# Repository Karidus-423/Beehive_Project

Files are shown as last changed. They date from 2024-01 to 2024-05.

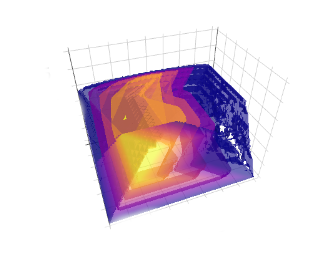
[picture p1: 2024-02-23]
Research_Beehive/images/Beehive-2.png

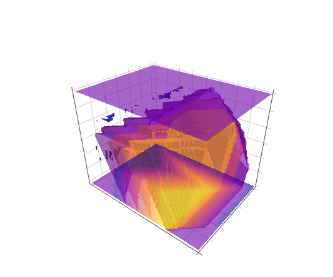
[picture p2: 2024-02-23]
Research_Beehive/images/Beehive-1.png

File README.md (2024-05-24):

# Beehive Project for Kentucky State University
___
The folders build up the project and each of them is responsible for a single 
aspect of it.

- [Datalogger_Beehive](https://github.com/Karidus-423/Beehive_Project/tree/main/Datalogger_Beehive) contains the arduino scripts and the schematics for Pcbs so that the can be printed and the data to get collected.
- [Research_Beehive](https://github.com/Karidus-423/Beehive_Project/tree/main/Research_Beehive) used to analyze the data and make graphs that can be used for science presentations and conferences.
- [Webapp_Beehive](https://github.com/Karidus-423/Beehive_Project/tree/main/Webapp_Beehive) where the webapp in which the output of the Datalogger will be used so that we areble to visualize the recordings of the data.

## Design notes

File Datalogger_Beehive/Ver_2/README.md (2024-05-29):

# Datalogger Version 2
___

### File Structure
- **enclosure**, here you'll find all of the 3D models for the datalogger enclosure.
- **pcb**, schemas, pcb schemas and drill files will be found here.
- **resources**, libraries that are used in making the schemas and pcbs.
- **script**, where the arduino scripts for the datalogger are saved.

## Schematic and PCB Design

At the moment there are 5 main components that are required for the circuit to work.

- Programming Board
- Sensors
- Battery
- Real Time Clock (RTC)
- SD Card Moudule

The main idea is to have the <u>Programming Board</u>, to be connected to a large
battery. The battery must be able to be charged quickly or be swapped quickly. The
sensors need to be configured in a way that the user is able to unplug them relatively
easily try to look for **Audio Jacks** with 3 pins. I have a 3D model of the overall
idea of what it should look like. The parts are already placed on the schematic.

Then the RTC and the SDCard are going to be rather simple as there are some modules
that are able to just connect directly to the feather boards that where ordered.
**Feather Footprint** is a standarized layout of a microcontroller that makes it
easier to get parts for it no matter the brand. The Sparkfun microcontroller and
the adalogger can just be mounted on each other for them to work correctly.

The **Sparkfun Microcontroller** is able to charge whatever battery is connected
to it at a rate of 500mAh. So that takes care of the chargin part. What I remains
are just the design of the PCB to be printed and piecing everything together. The
3D Printers at the university will also work. I will leave two models already printed
at the lab for them to be used as examples or as the enclosure itself.

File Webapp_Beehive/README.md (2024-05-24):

# Beesual: A 3D isograph visualizaton tool for the use of beehives.
Beesual is a visualization tool that renders a 3D isograph using plotly to view the changes in temperature inside a beehive. Built using Dash.

[.csv format for app to work.](https://raw.githubusercontent.com/Karidus-423/Bee_Hive_Webapp/main/sensor_data_hours_updated.csv)

# Bee Project Documentation
____
#### To run the app
```bash
cd Webapp_Beehive
python callbacks.py #Windows py callbacks.py
```

## Main Libraries used
- Numpy
- Pandas
- Scipy
- Plotly

## CSV Format
The CSV format that is generated by the datalogger has 11 columns which are ...
- Sensor Number
- Temperature Sensor Location
    - X
    - Y
    - Z
- Year
- Month
- Hour
- Minute
- Second
- Temperature Value
- Timestamp

<p>I have the full timestamp and the individual components of them like this so that
I'll be easier to extract specific formats when needed and have less code dedicated
to formatting the time in the frontend.</p>

There are three main files for the program to work at the moment.
- callbacks.py
- layout.py
- maindash.py

#### Callbacks
Is the main backend that reads the data and displays it as the 3D image.

Everything before `def update_dataset_and_figures(contents):` is just setup. 
The main building block that lets us speak back to the plotly library is with
the `@app.callback(Output,Input)`. You are able to have n outputs and n inputs by
sorrounding them with [].

`def update_dataset_and_figures(contents):` Is the main function that makes the 
main volume image. The documentation for how to use this is here. [Plotly Volume Plot](https://plotly.com/python/3d-volume-plots/).

Also the component that makes the transistion between the CSV to the graph possible
is...
```python
recording = dataset[dataset['Timestamp'] == first_timestamp]

X = np.linspace(recording['X'].min(), recording['X'].max(), 50)
Y = np.linspace(recording['Y'].min(), recording['Y'].max(), 50)
Z = np.linspace(recording['Z'].min(), recording['Z'].max(), 20)

x, y, z = np.meshgrid(X, Y, Z)

points = np.array((recording['X'], recording['Y'], recording['Z'])).T
temps = recording['Temperature']

newdata = griddata(points, temps, (x, y, z), method='linear')
```

Then depending on the slider values that are inputed we get the collection of dates
in which are then added to an array. That array then build every graph which make
the collection of them so that we can slide them and see it "animated".

#### Layout and Maindash
The layout file is the front end of the app. It uses the Dash Components [Dash Docs](https://dash.plotly.com/).
As the building blocks for the frontend and bootstrap for the styling. One could also
use javascript if you are willing to change it as it a bit hard to follow since everything
is really nested toghether. The **maindash.py** is just used to separate the two
files. The `app = dash.Dash()` is what is needed to run the project. As long as that
is read the project will run.

### Extra Resources
[Mesh Grid Insights](https://stackoverflow.com/questions/36013063/what-is-the-purpose-of-meshgrid-in-numpy)

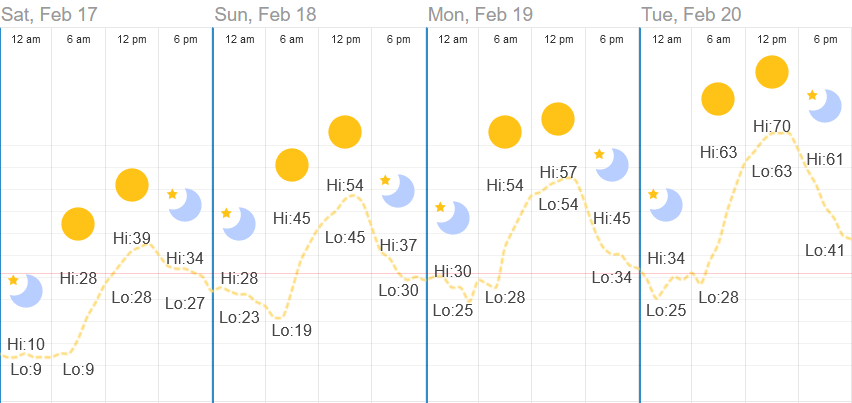
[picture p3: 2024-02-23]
Research_Beehive/images/weather.png

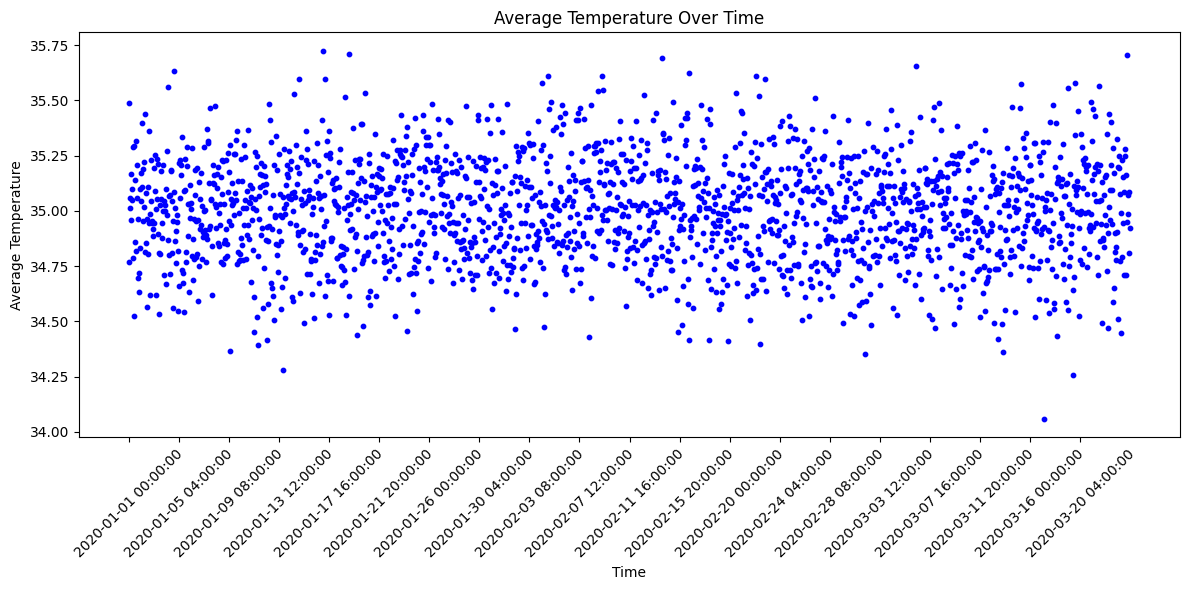
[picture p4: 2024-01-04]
Research_Beehive/images/averageTemp_time.png

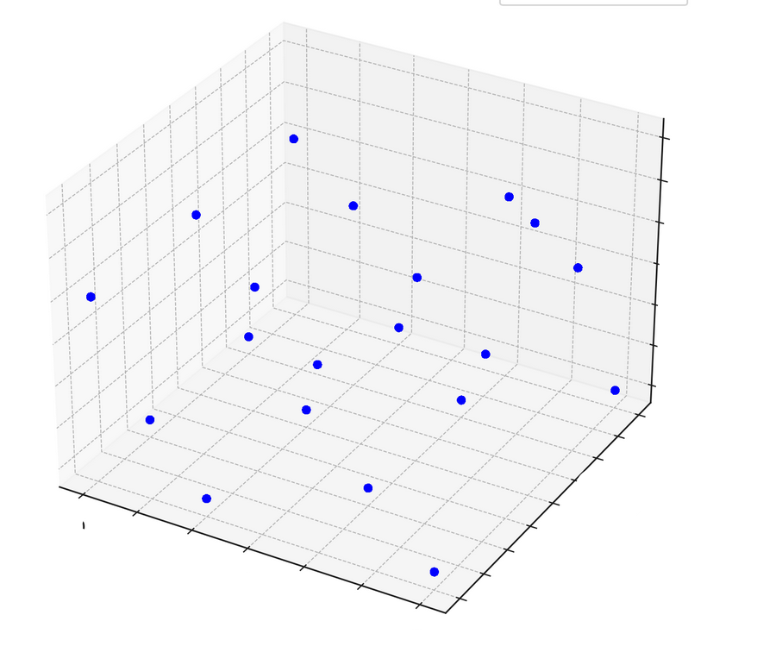
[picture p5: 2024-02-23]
Research_Beehive/images/Positions.png

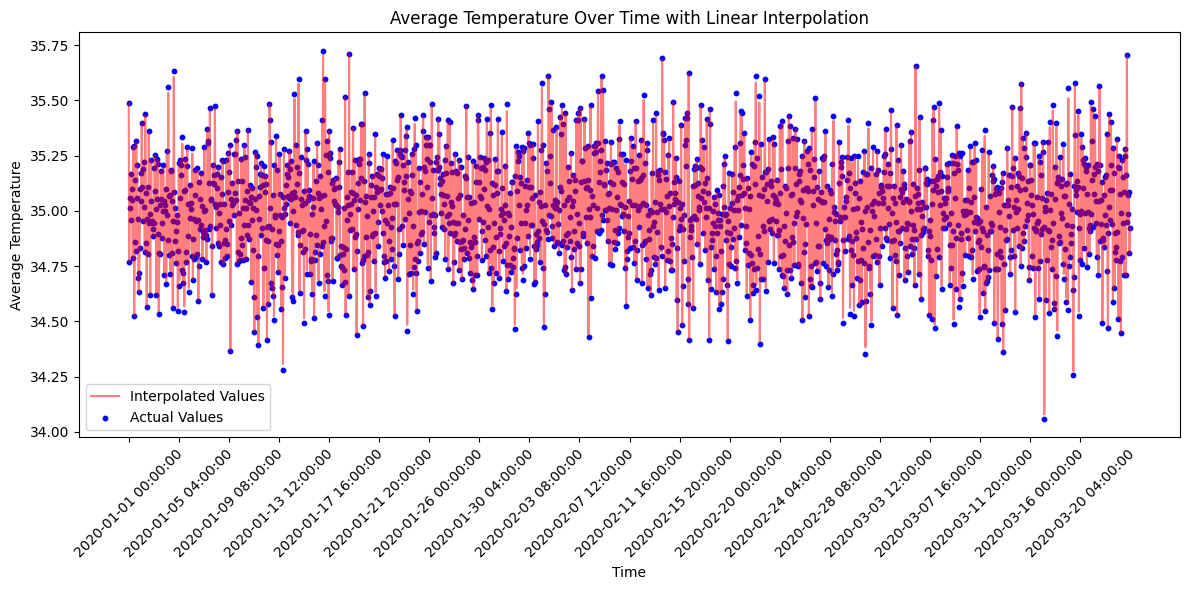
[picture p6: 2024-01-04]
Research_Beehive/images/interpolation.png

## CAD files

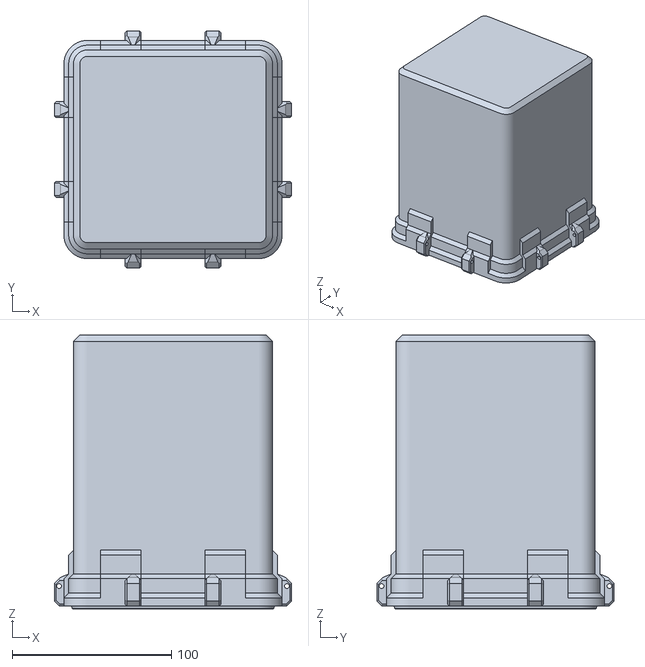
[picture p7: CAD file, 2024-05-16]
Datalogger_Beehive/Ver_2/enclosure/bottom.stl
149.0 x 149.0 x 172.0

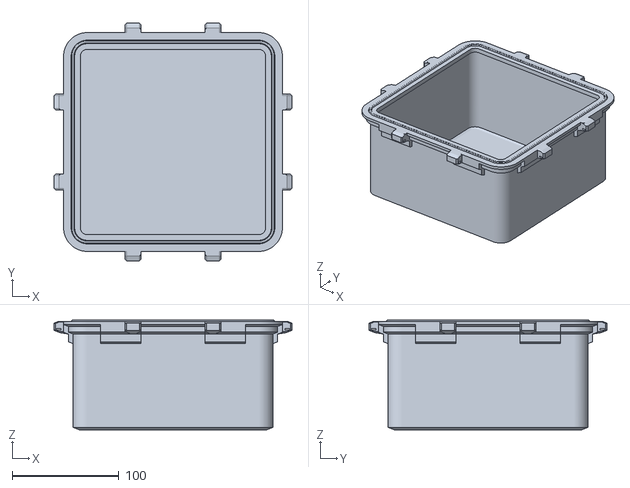
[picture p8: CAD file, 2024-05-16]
Datalogger_Beehive/Ver_2/enclosure/bottom_v2.stl
223.5 x 223.5 x 103.2

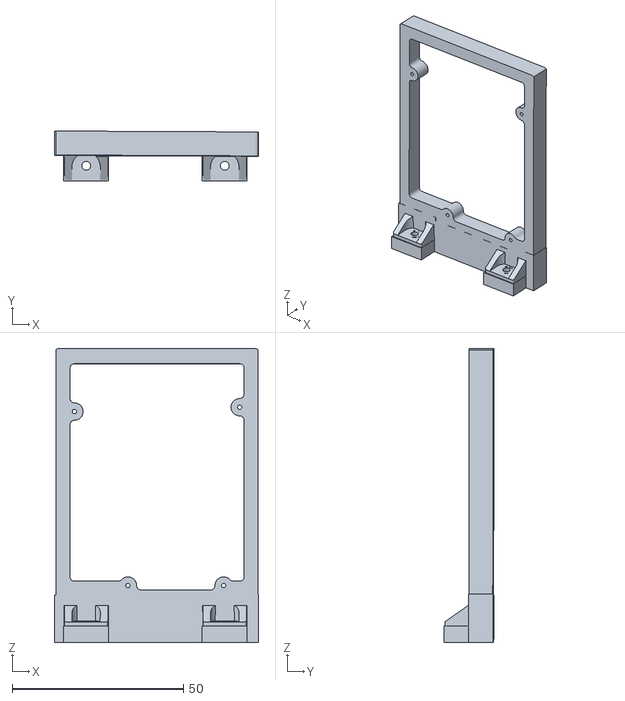
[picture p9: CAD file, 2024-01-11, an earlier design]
Datalogger_Beehive/Ver_1/3D_Models/Arduino_MOUNT.stl
59.6 x 14.6 x 85.8

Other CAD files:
Datalogger_Beehive/Ver_2/enclosure/datalogger_v2_enclosure.blend

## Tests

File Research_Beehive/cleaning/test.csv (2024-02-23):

Sensor_number | X | Y | Z | Year | Month | Day | Hour | Minute | Second | Temperature | Timestamp
11 | 3 | 3 | 0 | 2020 | 1 | 1 | 0 | 0 | 0 | 35.5 | 2020-01-01 00:00:00
3 | 3 | 1 | 0 | 2020 | 1 | 1 | 0 | 0 | 0 | 37.44 | 2020-01-01 00:00:00
4 | 2 | 0 | 1 | 2020 | 1 | 1 | 0 | 0 | 0 | 37.51 | 2020-01-01 00:00:00
5 | 2 | 0 | 1 | 2020 | 1 | 1 | 0 | 0 | 0 | 34.63 | 2020-01-01 00:00:00
6 | 2 | 4 | 1 | 2020 | 1 | 1 | 0 | 0 | 0 | 35.23 | 2020-01-01 00:00:00
7 | 1 | 1 | 2 | 2020 | 1 | 1 | 0 | 0 | 0 | 37.47 | 2020-01-01 00:00:00
8 | 1 | 4 | 0 | 2020 | 1 | 1 | 0 | 0 | 0 | 33.92 | 2020-01-01 00:00:00
9 | 0 | 8 | 2 | 2020 | 1 | 1 | 0 | 0 | 0 | 33.71 | 2020-01-01 00:00:00
10 | 0 | 5 | 1 | 2020 | 1 | 1 | 0 | 0 | 0 | 35.27 | 2020-01-01 00:00:00
13 | 1 | 3 | 0 | 2020 | 1 | 1 | 0 | 0 | 0 | 34.89 | 2020-01-01 00:00:00
14 | 1 | 8 | 2 | 2020 | 1 | 1 | 0 | 0 | 0 | 35.12 | 2020-01-01 00:00:00
15 | 3 | 4 | 1 | 2020 | 1 | 1 | 0 | 0 | 0 | 32.13 | 2020-01-01 00:00:00
12 | 3 | 8 | 0 | 2020 | 1 | 1 | 0 | 0 | 0 | 37.89 | 2020-01-01 00:00:00
18 | 1 | 9 | 2 | 2020 | 1 | 1 | 0 | 0 | 0 | 32.62 | 2020-01-01 00:00:00
20 | 3 | 2 | 0 | 2020 | 1 | 1 | 0 | 0 | 0 | 37.82 | 2020-01-01 00:00:00
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

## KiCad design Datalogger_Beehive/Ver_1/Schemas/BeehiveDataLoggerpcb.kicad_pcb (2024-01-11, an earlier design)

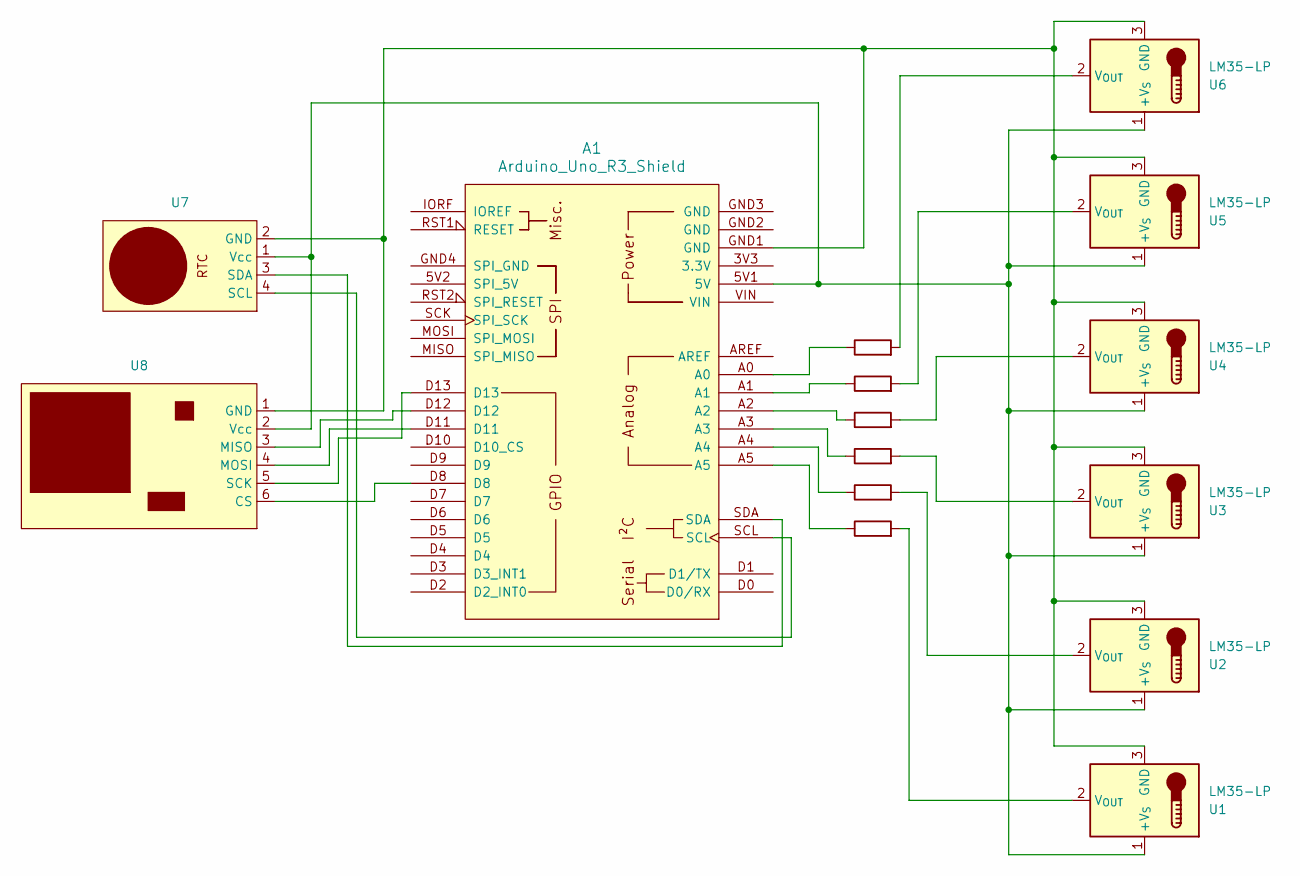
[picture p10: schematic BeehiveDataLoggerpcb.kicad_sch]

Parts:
A1: Arduino_Uno_R3_Shield
R1, R2, R3, R4, R5, R6: R; R_Axial_DIN0207_L6.3mm_D2.5mm_P7.62mm_Horizontal
U1, U2, U3, U4, U5, U6: LM35-LP; TO-92_Inline
U7: PinSocket_1x04_P2.54mm_Vertical
U8: PinSocket_1x06_P2.54mm_Vertical

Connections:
unnamed 0: A1.5V1 (5V), U1.1 (+V_{S}), U2.1 (+V_{S}), U3.1 (+V_{S}), U4.1 (+V_{S}), U5.1 (+V_{S}), U6.1 (+V_{S}), U7.1 (Vcc), U8.2 (Vcc); also elsewhere on the board
unnamed 1: A1.A0, R1.1; also elsewhere on the board
unnamed 2: A1.A1, R2.1; also elsewhere on the board
unnamed 3: A1.A2, R3.1; also elsewhere on the board
unnamed 4: A1.A3, R4.1; also elsewhere on the board
unnamed 5: A1.A4, R5.1; also elsewhere on the board
unnamed 6: A1.A5, R6.1; also elsewhere on the board
unnamed 7: A1.GND1 (GND), U1.3 (GND), U2.3 (GND), U3.3 (GND), U4.3 (GND), U5.3 (GND), U6.3 (GND), U7.2 (GND), U8.1 (GND); also elsewhere on the board
unnamed: R6.2, U1.2 (V_{OUT})
unnamed: R5.2, U2.2 (V_{OUT})
unnamed: R4.2, U3.2 (V_{OUT})
unnamed: R3.2, U4.2 (V_{OUT})
unnamed: R2.2, U5.2 (V_{OUT})
unnamed: R1.2, U6.2 (V_{OUT})
unnamed 14: A1.SCL, U7.4 (SCL); also elsewhere on the board
unnamed 15: A1.SDA, U7.3 (SDA); also elsewhere on the board
unnamed 16: A1.D8, U8.6 (CS); also elsewhere on the board
unnamed 17: A1.D12, U8.3 (MISO); also elsewhere on the board
unnamed 18: A1.D11, U8.4 (MOSI); also elsewhere on the board
unnamed 19: A1.D13, U8.5 (SCK); also elsewhere on the board

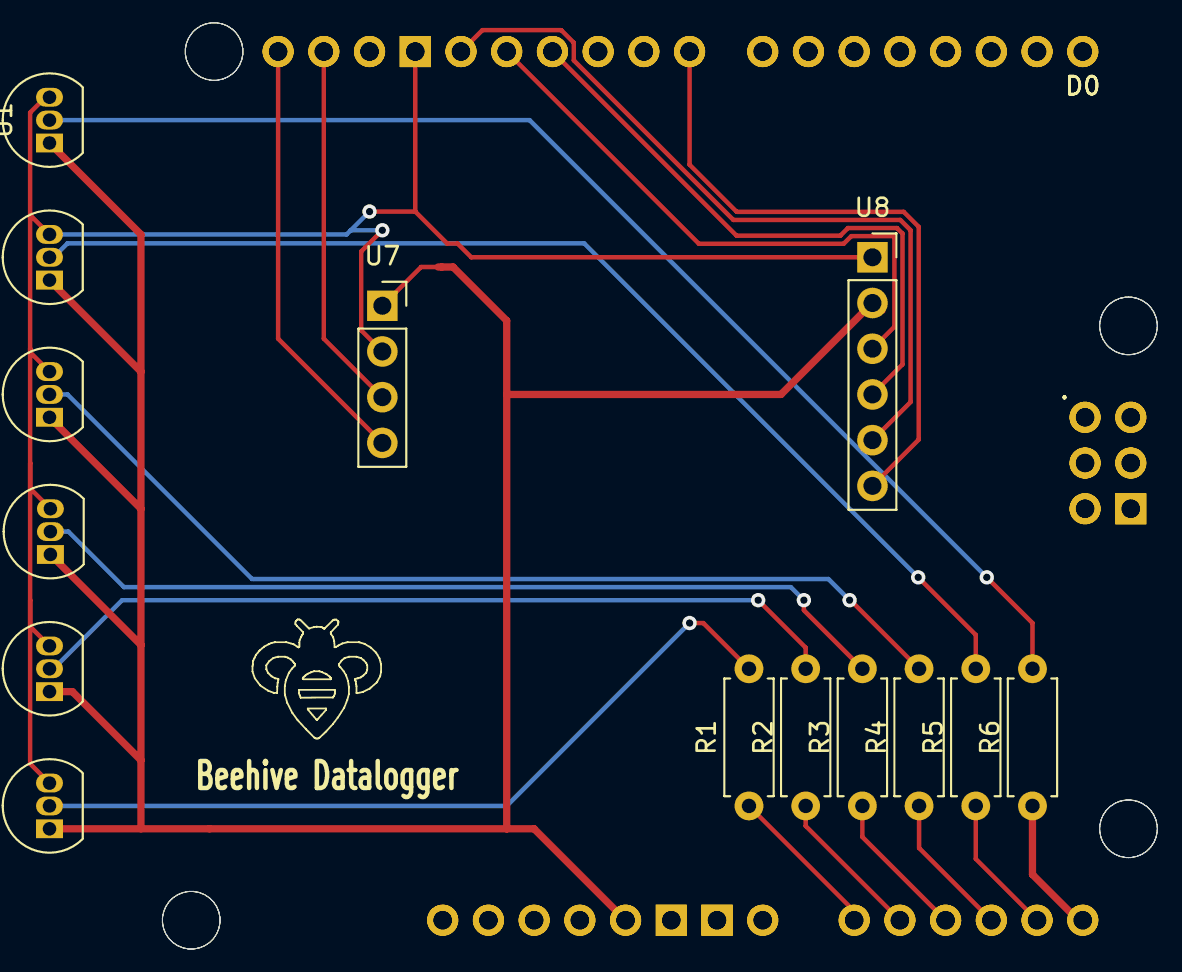
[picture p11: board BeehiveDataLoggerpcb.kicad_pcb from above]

Board: 2 copper layers, 16 parts (0 on the bottom side), 20 nets.

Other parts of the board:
A1#2: Arduino_Uno_R3_Shield

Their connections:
unnamed 0: A1#2.5V1 (5V); also elsewhere on the board
unnamed 1: A1#2.A0; also elsewhere on the board
unnamed 2: A1#2.A1; also elsewhere on the board
unnamed 3: A1#2.A2; also elsewhere on the board
unnamed 4: A1#2.A3; also elsewhere on the board
unnamed 5: A1#2.A4; also elsewhere on the board
unnamed 6: A1#2.A5; also elsewhere on the board
unnamed 7: A1#2.GND1 (GND); also elsewhere on the board
unnamed 14: A1#2.SCL; also elsewhere on the board
unnamed 15: A1#2.SDA; also elsewhere on the board
unnamed 16: A1#2.D8; also elsewhere on the board
unnamed 17: A1#2.D12; also elsewhere on the board
unnamed 18: A1#2.D11; also elsewhere on the board
unnamed 19: A1#2.D13; also elsewhere on the board

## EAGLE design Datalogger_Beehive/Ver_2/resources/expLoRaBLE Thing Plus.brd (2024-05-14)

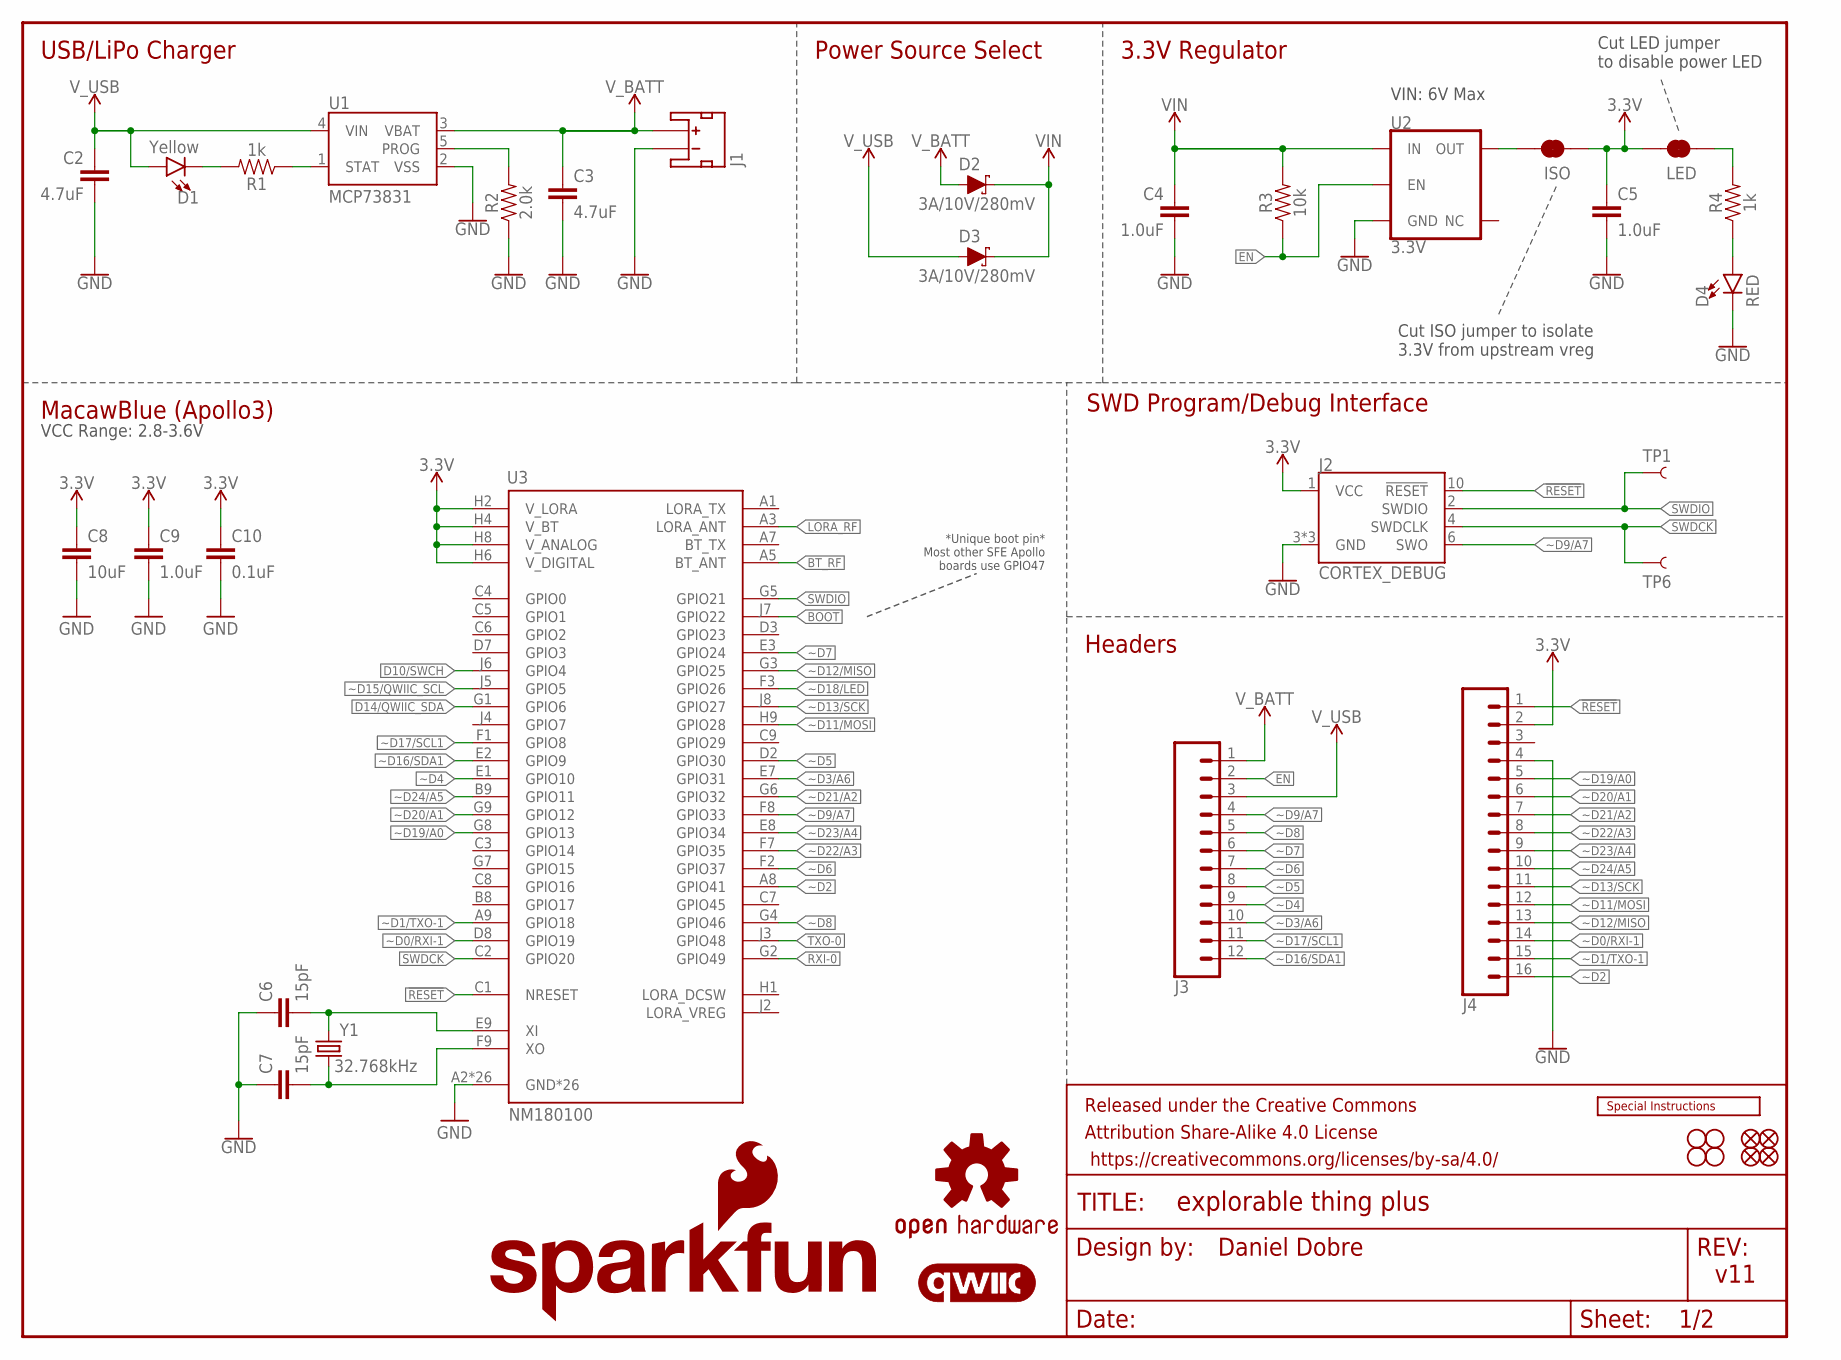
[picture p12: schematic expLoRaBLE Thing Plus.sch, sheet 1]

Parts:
C2, C3: 4.7uF; 0603
C4, C5, C9: 1.0uF; 0603
C6, C7: 15pF; 0603
C8: 10uF; 0603
C10: 0.1uF; 0603
D1: Yellow; LED-0603
D2, D3: 3A/10V/280mV; SOD-323
D4: RED; LED-0603
FD1, FD2, FD3, FD4: FIDUCIALUFIDUCIAL; FIDUCIAL-MICRO
FRAME1: FRAME-LETTER; CREATIVE_COMMONS
H1, H2, H3, H4: STAND-OFF
ISO: JUMPER-SMT_2_NC_TRACE_SILK; SMT-JUMPER_2_NC_TRACE_SILK
J1: JST_2MM_MALE; JST-2-SMD
J2: CORTEX_DEBUG; 2X5-PTH-1.27MM-NO_SILK
J3: CONN_12SM_SQ_NO_SILK; 1X12_SM_SQ_NOSILK
J4: CONN_161X16_SM_SQ_NOSILK; 1X16_SM_SQ_NOSILK
LED: JUMPER-SMT_2_NC_TRACE_SILK; SMT-JUMPER_2_NC_TRACE_SILK
LOGO1: OSHW-LOGOS; OSHW-LOGO-S
LOGO2: QWIIC_LOGO_5MM; QWIIC_5MM
LOGO3: SFE_LOGO_NAME_FLAME.1_INCH; SFE_LOGO_NAME_FLAME_.1
LOGO4: SPECIAL_INSTRUCTIONS-ORDERING; ORDERING_INSTRUCTIONS
R1, R4: 1k; 0603
R2: 2.0k; 0603
R3: 10k; 0603
TP1, TP6: TEST-POINTTP_15TH_THRU; TP_15TH
U1: MCP73831; SOT23-5
U2: 3.3V; SOT23-5
U3: NM180100; LGA81
Y1: 32.768kHz; CRYSTAL-SMD-3.2X1.5MM

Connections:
3.3V: C5.1, C8.1, C9.1, C10.1, ISO.1, J2.1 (VCC), J4.2, LED.2, U3.H2 (V_LORA), U3.H4 (V_BT), U3.H6 (V_DIGITAL), U3.H8 (V_ANALOG); also elsewhere on the board
!RESET: J2.10 (!RESET), J4.1, U3.C1 (NRESET); also elsewhere on the board
BOOT: U3.J7 (GPIO22); also elsewhere on the board
BT_RF: U3.A5 (BT_ANT); also elsewhere on the board
D10/SWCH: U3.J6 (GPIO4); also elsewhere on the board
D14/QWIIC_SDA: U3.G1 (GPIO6); also elsewhere on the board
EN: J3.2, R3.1, U2.3 (EN)
GND: C2.2, C3.2, C4.2, C5.2, C6.1, C7.1, C8.2, C9.2, C10.2, D4.C, J1.1 (-), J2.3 (GND), J2.5 (GND), J2.9 (GND), J4.4, R2.1, U1.2 (VSS), U2.2 (GND), U3.A2 (GND*26), U3.A4 (GND*26), U3.A6 (GND*26), U3.B1 (GND*26), U3.B2 (GND*26), U3.B3 (GND*26), U3.B4 (GND*26), U3.B5 (GND*26), U3.B6 (GND*26), U3.B7 (GND*26), U3.D1 (GND*26), U3.D4 (GND*26), U3.D5 (GND*26), U3.D6 (GND*26), U3.D9 (GND*26), U3.E4 (GND*26), U3.E5 (GND*26), U3.E6 (GND*26), U3.F4 (GND*26), U3.F5 (GND*26), U3.F6 (GND*26), U3.H3 (GND*26), U3.H5 (GND*26), U3.H7 (GND*26), U3.J1 (GND*26), U3.J9 (GND*26); also elsewhere on the board
LORA_RF: U3.A3 (LORA_ANT); also elsewhere on the board
unnamed: R2.2, U1.5 (PROG)
unnamed: C7.2, U3.F9 (XO), Y1.P$2 (2)
unnamed: D1.C, R1.2
unnamed: R1.1, U1.1 (STAT)
unnamed: LED.1, R4.2
unnamed: C6.2, U3.E9 (XI), Y1.P$1 (1)
unnamed: D4.A, R4.1
unnamed: ISO.2, U2.5 (OUT)
RXI-0: U3.G2 (GPIO49); also elsewhere on the board
SWDCK: J2.4 (SWDCLK), TP6.P$1, U3.C2 (GPIO20)
SWDIO: J2.2 (SWDIO), TP1.P$1, U3.G5 (GPIO21)
TXO-0: U3.J3 (GPIO48); also elsewhere on the board
VIN: C4.1, D2.C, D3.C, R3.2, U2.1 (IN)
V_BATT: C3.1, D2.A, J1.2 (+), J3.1, U1.3 (VBAT)
V_USB: C2.1, D1.A, D3.A, J3.3, U1.4 (VIN); also elsewhere on the board
~D0/RXI-1: J4.14, U3.D8 (GPIO19)
~D1/TXO-1: J4.15, U3.A9 (GPIO18)
~D2: J4.16, U3.A8 (GPIO41)
~D3/A6: J3.10, U3.E7 (GPIO31)
~D4: J3.9, U3.E1 (GPIO10)
~D5: J3.8, U3.D2 (GPIO30)
~D6: J3.7, U3.F2 (GPIO37)
~D7: J3.6, U3.E3 (GPIO24)
~D8: J3.5, U3.G4 (GPIO46)
~D9/A7: J2.6 (SWO), J3.4, U3.F8 (GPIO33)
~D11/MOSI: J4.12, U3.H9 (GPIO28)
~D12/MISO: J4.13, U3.G3 (GPIO25)
~D13/SCK: J4.11, U3.J8 (GPIO27)
~D15/QWIIC_SCL: U3.J5 (GPIO5); also elsewhere on the board
~D16/SDA1: J3.12, U3.E2 (GPIO9)
~D17/SCL1: J3.11, U3.F1 (GPIO8)
~D18/LED: U3.F3 (GPIO26); also elsewhere on the board
~D19/A0: J4.5, U3.G8 (GPIO13)
~D20/A1: J4.6, U3.G9 (GPIO12)
~D21/A2: J4.7, U3.G6 (GPIO32)
~D22/A3: J4.8, U3.F7 (GPIO35)
~D23/A4: J4.9, U3.E8 (GPIO34)
~D24/A5: J4.10, U3.B9 (GPIO11)

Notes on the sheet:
SWD Program/Debug Interface
Headers
MacawBlue (Apollo3)
USB/LiPo Charger
Power Source Select
3.3V Regulator
VIN: 6V Max
Daniel Dobre
v11
Cut LED jumper to disable power LED
Cut ISO jumper to isolate 3.3V from upstream vreg
VCC Range: 2.8-3.6V
*Unique boot pin* Most other SFE Apollo boards use GPIO47

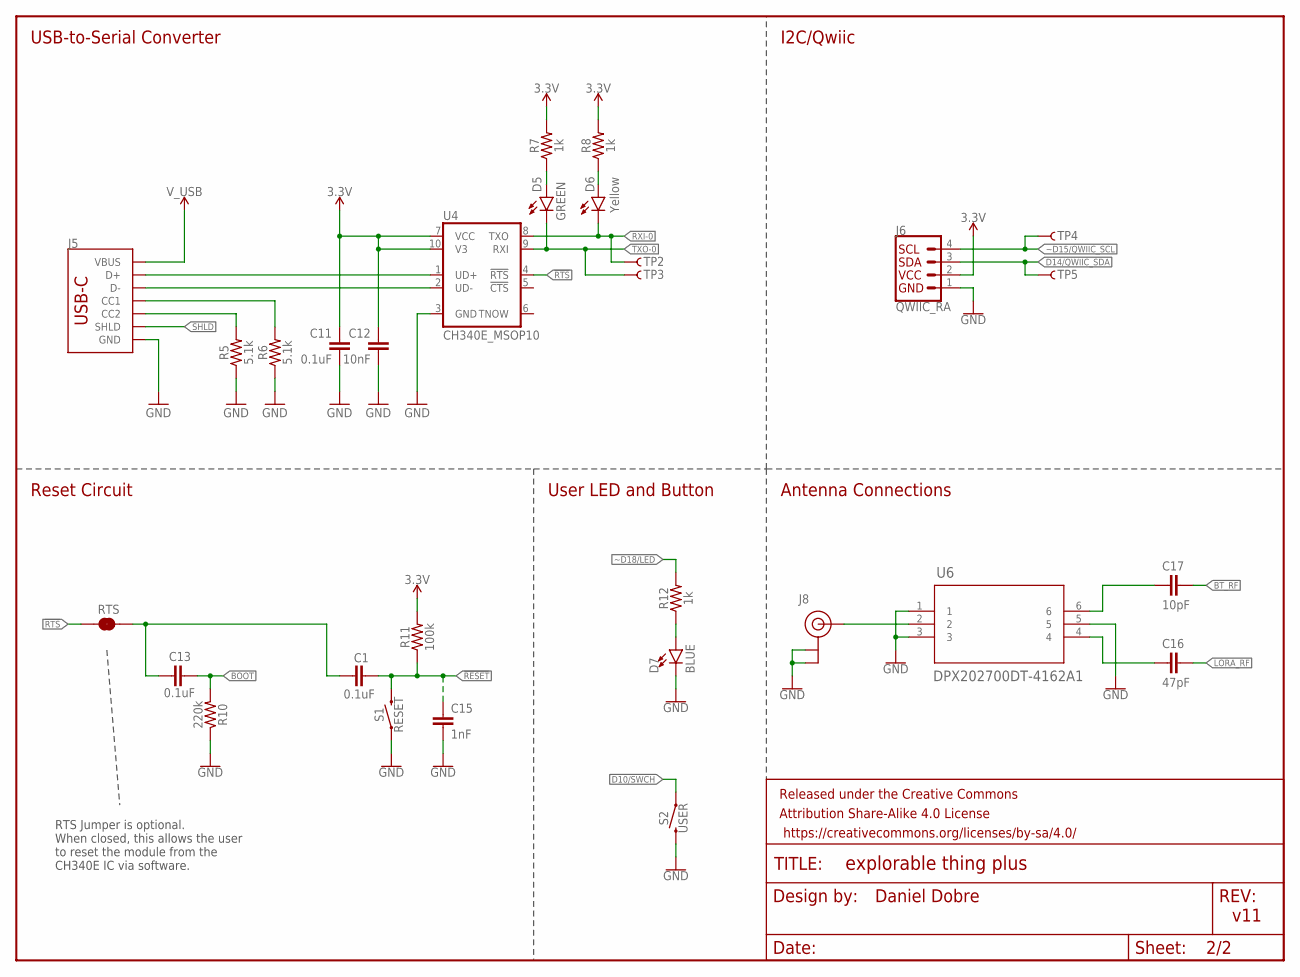
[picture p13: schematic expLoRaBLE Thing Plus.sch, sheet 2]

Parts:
C1, C11, C13: 0.1uF; 0603
C12: 10nF; 0603
C15: 1nF; 0603
C16: 47pF; 0603
C17: 10pF; 0603
D5: GREEN; LED-0603
D6: Yellow; LED-0603
D7: BLUE; LED-0603
FRAME2: FRAME-LETTERNO_PACKAGE; DUMMY
J5: USB Female Type C Connector; USB-C-16P-4LAYER-ISOLATED
J6: QWIIC_RA; JST04_1MM_RA
J8: U.FL
R5, R6: 5.1k; 0603
R7, R8, R12: 1k; 0603
R10: 220k; 0603
R11: 100k; 0603
RTS: JUMPER-SMT_2_NC_TRACE_SILK; SMT-JUMPER_2_NC_TRACE_SILK
S1: RESET; TACTILE_SWITCH_SMD_4.6X2.8MM
S2: USER; TACTILE_SWITCH_SMD_4.6X2.8MM
TP2, TP3, TP4, TP5: TEST-POINTTP_15TH_THRU; TP_15TH
U4: CH340E_MSOP10; MSOP10
U6: DPX202700DT-4162A1; RF_4060A1_TDK

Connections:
3.3V: C11.1, C12.1, J6.2, R7.2, R8.2, R11.2, U4.7 (VCC), U4.10 (V3); also elsewhere on the board
!RESET: C1.2, C15.1, R11.1, S1.3 (2), S1.4 (2); also elsewhere on the board
!RTS: RTS.1, U4.4 (!RTS)
BOOT: C13.2, R10.2; also elsewhere on the board
BT_RF: C17.1; also elsewhere on the board
CC1: J5.A5 (CC1), R6.2
CC2: J5.B5 (CC2), R5.2
D10/SWCH: S2.1, S2.2 (1); also elsewhere on the board
D14/QWIIC_SDA: J6.3, TP5.P$1; also elsewhere on the board
D+1: J5.A6 (D+), J5.B6 (D+), U4.1 (UD+)
D-1: J5.A7 (D-), J5.B7 (D-), U4.2 (UD-)
GND: C11.2, C12.2, C15.2, D7.C, J5.GND, J5.GND2 (GND), J6.1, J8.1 (GND), J8.2 (GND), R5.1, R6.1, R10.1, S1.1, S1.2 (1), S2.3 (2), S2.4 (2), U4.3 (GND), U6.1, U6.3, U6.5; also elsewhere on the board
LORA_RF: C16.1; also elsewhere on the board
unnamed: D5.A, R7.1
unnamed: D7.A, R12.1
unnamed: D6.A, R8.1
unnamed: C17.2, U6.6
unnamed: J8.FEED (SIGNAL), U6.2
unnamed: C16.2, U6.4
unnamed: C1.1, C13.1, RTS.2
RXI-0: D6.C, TP2.P$1, U4.8 (TXO); also elsewhere on the board
SHLD: J5.SHLD1 (SHLD), J5.SHLD2 (SHLD), J5.SHLD3 (SHLD), J5.SHLD4 (SHLD), J5.SHLD5 (SHLD), J5.SHLD6 (SHLD), J5.SHLD7 (SHLD), J5.SHLD8 (SHLD)
TXO-0: D5.C, TP3.P$1, U4.9 (RXI); also elsewhere on the board
V_USB: J5.VBUS1 (VBUS), J5.VBUS2 (VBUS); also elsewhere on the board
~D15/QWIIC_SCL: J6.4, TP4.P$1; also elsewhere on the board
~D18/LED: R12.2; also elsewhere on the board

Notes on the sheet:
Antenna Connections
USB-to-Serial Converter
Reset Circuit
User LED and Button
I2C/Qwiic
Daniel Dobre
v11
RTS Jumper is optional. When closed, this allows the user to reset the module from the CH340E IC via software.

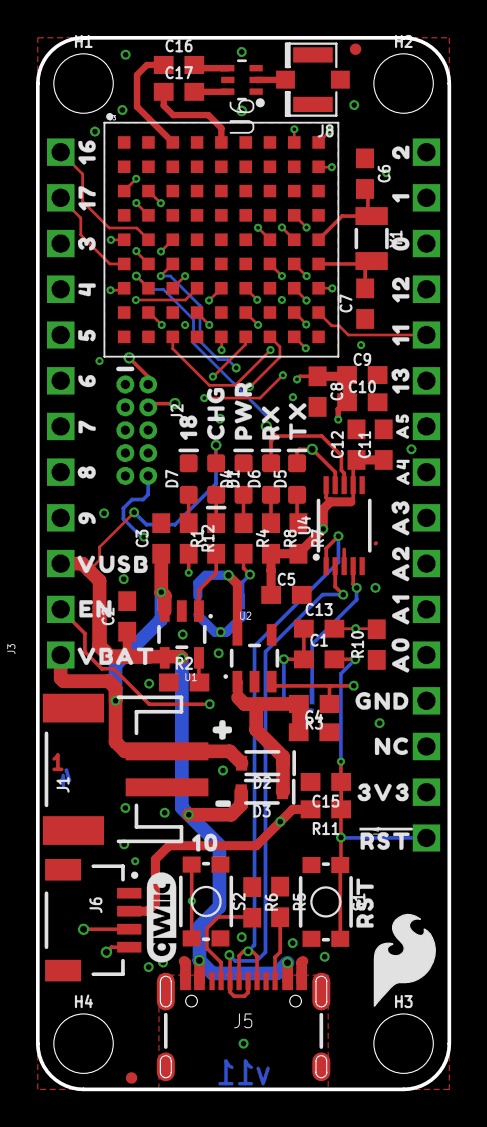
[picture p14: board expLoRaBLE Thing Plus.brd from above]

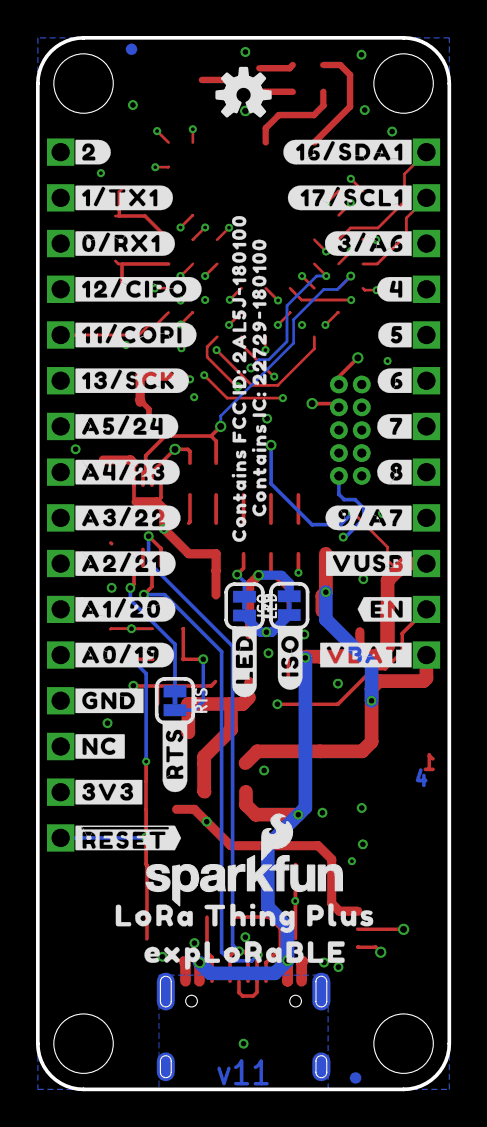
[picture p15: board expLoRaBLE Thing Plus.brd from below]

Board: 4 copper layers, 22.9 x 58.4 mm, 146 parts (42 on the bottom side), 60 nets.

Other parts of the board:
U$1: #16#SDA1#0
U$2: LORA_THING_PLUS0
U$3: EXPLORABLE0
U$4: #17#SCL1#0
U$5: #3#A6#0
U$6: #4#0
U$7: #5#0
U$8: #6#0
U$9: #7#0
U$10: #8#0
U$11: #9#A7#0
U$12: #VUSB#0
U$13: VUSB0
U$14: #EN#0
U$15: #VBAT#0
U$16: #2#0
U$17: #1#TX1#0
U$18: #0#RX1#0
U$19: #12#CIPO#0
U$20: #11#COPI#0
U$21: #13#SCK#0
U$22: CONTAINS_FCC_ID#_2AL5J#1801000
U$23: CONTAINS_IC#_22729#1801000
U$24: #RTS#0
U$28: #GND#0
U$29: #NC#0
U$30: #3V3#0
U$31: ##RESET##0
U$32: #LED#0
U$33: #A0#19#0
U$34: #ISO#0
U$35: #A1#20#0
U$36: #A2#21#0
U$37: #A3#22#0
U$38: #A4#23#0
U$39: #A5#24#0
U$62: 180
U$64: FOUR_LAYER_WARNING
U$65: SFE_LOGO_FLAME_.2
U$66: 160
U$67: CHG0
U$68: PWR0
U$69: 170
U$70: 30
U$71: 40
U$72: 50
U$73: 60
U$74: 70
U$75: 80
U$76: 90
U$78: EN0
U$79: VBAT0
U$80: 20
U$81: 10
U$82: 00
U$83: 120
U$84: 110
U$85: 130
U$86: A50
U$87: A40
U$88: A30
U$89: A20
U$90: A10
U$91: A00
U$92: GND0
U$93: NC0
U$94: 3V30
U$95: #RST#0
U$96: RST0
U$97: 100
U$98: #0
U$99: #_0
U$100: RX0
U$101: TX0

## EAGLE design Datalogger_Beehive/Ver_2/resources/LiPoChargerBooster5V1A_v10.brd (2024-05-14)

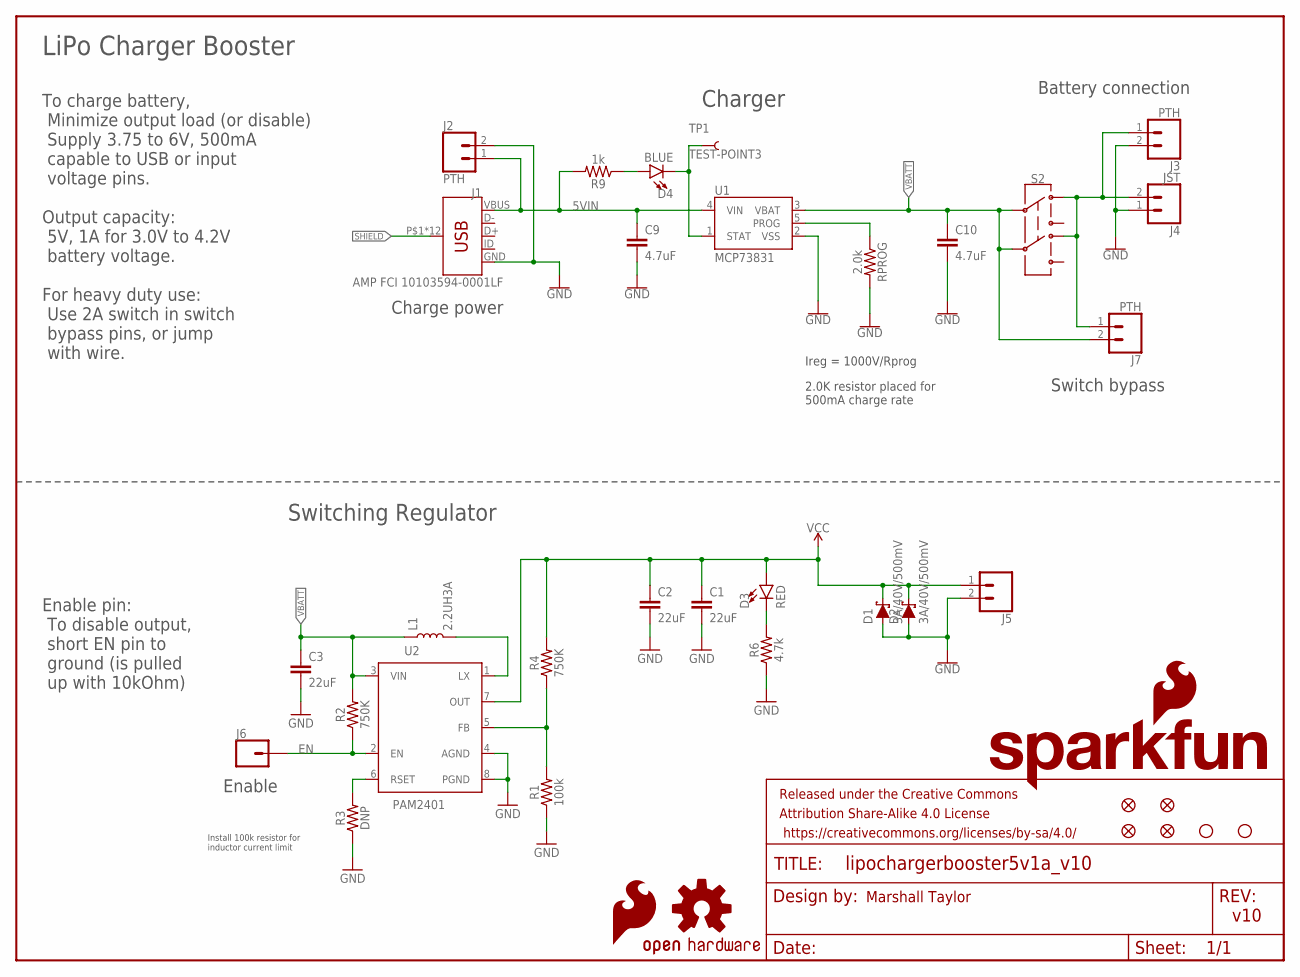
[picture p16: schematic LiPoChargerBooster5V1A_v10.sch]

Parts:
C1, C2, C3: 22uF; 0805
C9, C10: 4.7uF; 0603
D1, D2: 3A/40V/500mV; SMA-DIODE
D3: RED; LED-0603
D4: BLUE; LED-0603
FRAME1: FRAME-LETTER; CREATIVE_COMMONS
J1: AMP FCI 10103594-0001LF; USB-MICROB-PTH
J2, J3, J7: PTH; 1X02
J4: JST; JST-2-SMD
J5: CONN_02; 1X02
J6: CONN_01; 1X01
JP1, JP2, JP4, JP16: FIDUCIAL1X2; FIDUCIAL-1X2
JP3: SFE_LOGO_NAME_FLAME.1_INCH; SFE_LOGO_NAME_FLAME_.1
JP6, JP7: STAND-OFF
L1: 2.2UH3A; INDUCTOR_4X4MM
LOGO1: SFE_LOGO_FLAME.1_INCH; SFE_LOGO_FLAME_.1
R1: 100k; 0603
R2, R4: 750K; 0603
R3: DNP; 0603
R6: 4.7k; 0603
R9: 1k; 0603
RPROG: 2.0k; 0603
S2: SWITCH-DPDT-SMD-AYZ0202; SWITCH_DPDT_SMD_AYZ0202
TP1: TEST-POINT3; PAD.03X.03
U1: MCP73831; SOT23-5
U2: PAM2401; MSOP8
U$1: OSHW-LOGOS; OSHW-LOGO-S

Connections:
5VIN: C9.1, J1.VBUS, J2.1, R9.2, U1.4 (VIN)
EN: J6.1, R2.1, U2.2 (EN)
GND: C1.2, C2.2, C3.2, C9.2, C10.2, D1.A, D2.A, J1.GND, J2.2, J3.2, J4.1 (2), J5.2, R1.1, R3.1, R6.1, RPROG.2, U1.2 (VSS), U2.4 (AGND), U2.8 (PGND)
unnamed: D3.C, R6.2
unnamed: D4.A, R9.1
unnamed: L1.P$2 (2), U2.1 (LX)
unnamed: R3.2, U2.6 (RSET)
unnamed: J3.1, J4.2 (1), J7.1, S2.1, S2.4
unnamed: RPROG.1, U1.5 (PROG)
unnamed: R1.2, R4.1, U2.5 (FB)
unnamed: D4.C, TP1.P$1, U1.1 (STAT)
SHIELD: J1.P$1 (SHIELD), J1.P$2 (SHIELD), J1.P$3 (SHIELD), J1.P$4 (SHIELD), J1.P$6 (SHIELD), J1.P$8 (SHIELD), J1.P$10 (SHIELD), J1.P$12 (SHIELD), J1.SHEILD2 (SHIELD), J1.SHIELD, J1.SHIELD3 (SHIELD), J1.SHIELD4 (SHIELD)
VBATT: C3.1, C10.1, J7.2, L1.P$1 (1), R2.2, S2.2, S2.5, U1.3 (VBAT), U2.3 (VIN)
VCC: C1.1, C2.1, D1.C, D2.C, D3.A, J5.1, R4.2, U2.7 (OUT)

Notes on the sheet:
Charger
Switching Regulator
Marshall Taylor
v10
2.0K resistor placed for 500mA charge rate
Ireg = 1000V/Rprog
To charge battery, Minimize output load (or disable) Supply 3.75 to 6V, 500mA capable to USB or input voltage pins.
Install 100k resistor for inductor current limit
LiPo Charger Booster
Output capacity: 5V, 1A for 3.0V to 4.2V battery voltage.
Enable pin: To disable output, short EN pin to ground (is pulled up with 10kOhm)
Enable
Charge power
Battery connection
Switch bypass
For heavy duty use: Use 2A switch in switch bypass pins, or jump with wire.

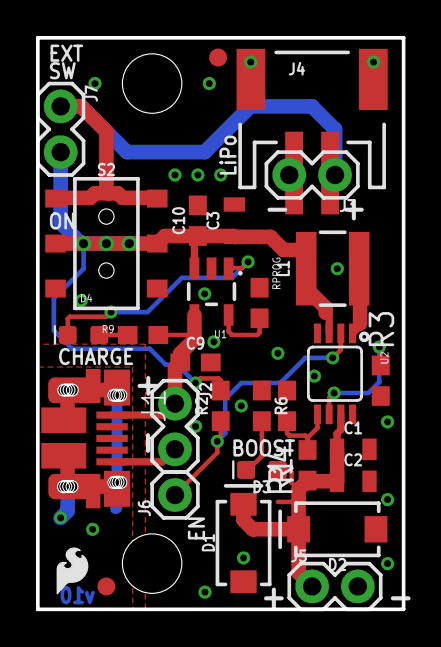
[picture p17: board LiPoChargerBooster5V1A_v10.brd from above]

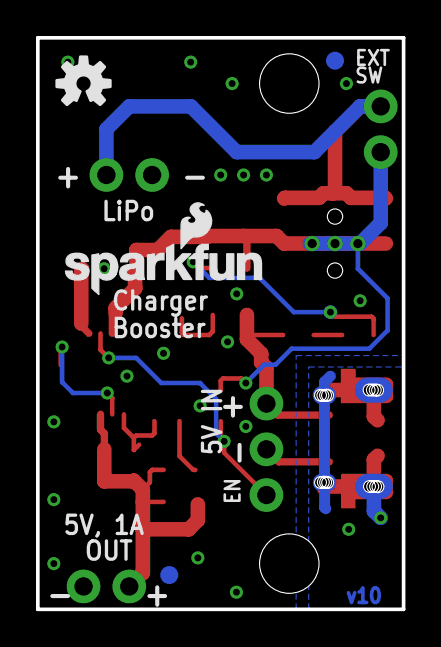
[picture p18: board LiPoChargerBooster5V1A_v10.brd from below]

Board: 2 copper layers, 20.3 x 31.8 mm, 38 parts (5 on the bottom side), 14 nets.

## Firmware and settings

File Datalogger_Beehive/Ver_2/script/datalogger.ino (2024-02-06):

// Include the required Arduino libraries:
#include "OneWire.h"
#include "DallasTemperature.h"
#include "RTClib.h"
#include "SD.h"
#include "SPI.h"

RTC_PCF8523 rtc;
// Define to which pin of the Arduino the 1-Wire bus is connected:
#define ONE_WIRE_BUS 4
// Create a new instance of the oneWire class to communicate with any OneWire device:
OneWire oneWire(ONE_WIRE_BUS);
// Pass the oneWire reference to DallasTemperature library:
DallasTemperature sensors(&oneWire);

//SD card variables
const int chipSelect = 6;

int deviceCount = 0;
float tempC;
float tempF;

void setup() {
  // Begin serial communication at a baud rate of 9600:
  Serial.begin(9600);
  while(!Serial);
  // Start up the library:
  sensors.begin();

  // Locate the devices on the bus:
  Serial.println("Locating devices...");
  Serial.print("Found ");
  deviceCount = sensors.getDeviceCount();
  Serial.print(deviceCount);
  Serial.println(" devices");

  //SD card Initialization
  Serial.print("Initializing SD card..");
  if (!SD.begin(chipSelect)){
    Serial.println("Card failed, or not present");
    while(1);
  }
  //RTC Initialization
  Serial.println("Scanning for clock..");
  if (! rtc.begin()) {
    Serial.println("Couldn't find RTC");
    Serial.flush();
    while(1) delay(10);
  }
  if (! rtc.initialized() || rtc.lostPower()) {
    Serial.println("RTC is NOT initialized, let's set the time!");
    rtc.adjust(DateTime(2024, 2, 5, 6, 40, 0));
  }
  rtc.start();

}

void loop() {
  // Send the command for all devices on the bus to perform a temperature conversion:
  sensors.requestTemperatures();
  String dataString = "";

  // Open the file for writing at the beginning of the loop
  File dataFile = SD.open("datalog.txt", FILE_WRITE);

  // Check if the file opened successfully
  if (dataFile) {
    // Display temperature from each sensor
    for (int i = 0; i < deviceCount; i++) {
      Serial.print("Sensor ");
      Serial.print(i + 1);
      Serial.print(" : ");
      tempC = sensors.getTempCByIndex(i);
      tempF = sensors.getTempFByIndex(i);
      Serial.print(tempC);
      Serial.print(" \xC2\xB0"); // shows degree symbol
      Serial.print("C  |  ");
      Serial.print(tempF);
      Serial.print(" \xC2\xB0"); // shows degree symbol
      Serial.println("F");

      // Construct the data entry string
      String entry = "S_" + String(i+1) + ", " + String(tempC) + " \xC2\xB0" + "C, " + getTimeString();

      // Append the entry to the data string
      dataString += entry;
    }

    // Write the complete data string to the file
    dataFile.println(dataString);

    // Close the file at the end of the loop
    dataFile.close();
  } else {
    Serial.println("error opening datalog.txt");
  }

  // Delay at the end of the loop
  delay(1000);
}


String getTimeString() {
  DateTime now = rtc.now();
  String dateString = String(now.month(), DEC) + "/" + String(now.day(), DEC) + "/" + String(now.year(), DEC);
  String timeString = String(now.hour(), DEC) + ":" + String(now.minute(), DEC) + ":" + String(now.second(), DEC);
  return dateString + " " + timeString + "\n";
}

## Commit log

2024-01-04 Renamed Folder
    Made new directory for digital sensors datalogger
2024-01-11 Added 3D models and Schemas
    [Arduino_MOUNT.stl, BeehiveDataLoggerpcb.kicad_pcb, BeehiveDataLoggerpcb.kicad_sch]
2024-02-06 Added code for digital sensors
    [Digital_Datalogger.kicad_pcb, Digital_Datalogger.kicad_sch]
2024-05-14 pcb update
    [Digital_Datalogger.kicad_pcb, Digital_Datalogger.kicad_sch, LiPoChargerBooster5V1A_v10.brd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]
2024-05-16 enclosure adding
    [Arduino_MOUNT.stl, BeehiveDataLoggerpcb.kicad_pcb, BeehiveDataLoggerpcb.kicad_sch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]
2024-06-13 sensor_data from datalogger
    [sd_card_data.csv]

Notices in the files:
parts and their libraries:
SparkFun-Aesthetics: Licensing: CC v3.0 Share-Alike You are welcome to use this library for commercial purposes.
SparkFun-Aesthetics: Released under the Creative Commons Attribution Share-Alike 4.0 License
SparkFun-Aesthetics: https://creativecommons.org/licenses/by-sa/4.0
